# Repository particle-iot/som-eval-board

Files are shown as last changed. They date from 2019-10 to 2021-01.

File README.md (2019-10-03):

# M.2 SoM Evaluation Board

*Hardware repository for the M.2 SoM evaluation board*

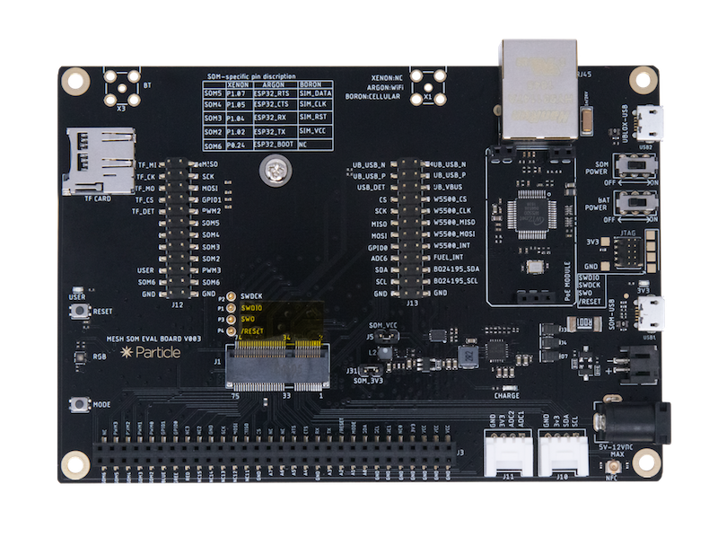
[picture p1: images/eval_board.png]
Eval Board


The description of the board and its features can be found in the documentation:

[https://docs.particle.io/datasheets/cellular/b-series-eval-board/](https://docs.particle.io/datasheets/cellular/b-series-eval-board/)

In this repository you can find the following directories:

- eagle: The [Eagle CAD](https://www.autodesk.com/products/eagle/overview) design files for this board. Note that it is a 4-layer board so you won't be able to edit it with the free version.
- gerbers: The Gerber files used to manufacture the board.
- bom: The bill of materials (Excel spreadsheet).

Other useful resources include:

- [Creating your first SoM board tutorial](https://docs.particle.io/tutorials/hardware-projects/som-first-board/).
- [AN001 Basic SoM Design](https://github.com/particle-iot/app-notes/tree/master/AN001-Basic-SoM-Design) is a simple SoM base board. Like a Boron it can be powered by LiPo battery, USB, or an external DC supply. It includes: RGB LED, bq24195 PMIC, MAX17043 Fuel Gauge, USB Connector, LiPo Connector (JST-PH), and M.2 SoM Connector. It is a 2-layer board.

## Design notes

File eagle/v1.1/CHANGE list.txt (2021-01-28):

2020/2/28
M2EVB change list:

1.Change the stand-off package,the stand-off hole size is 3.6mm.The pcb package hole size is 3.75mm.

2.change silkscreen Font into vector

3.Change silkscreen `UBLOX USB` to `Cellular-USB`

4.Add silkscreen `SOM AREA`

5.Connect unused pins on M.2 to the header,Including these signals:
SOM0,SOM1,SOM12~SOM18.

6.Change the 60pin of the 60pin female connector from NC to SOM9, 
and 59pin from SOM9 to GND for easy connection with SIM adapter

7.Change the SMA connector silk screen to "ANTENNA_1", "ANTENNA_2", "V1.1" & "CELLULAR_USB"

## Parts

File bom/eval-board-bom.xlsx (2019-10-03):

Description | Designator | Qty | MFG | MPN | MFG1 | MPN1
Ceramic Capacitor X6S 1uF 0402 6.3V ±10% ROHS | C2 | 1 | Samsung | CL05X105KQ5NNNC
CAP CER 0.1uF 16V X7R 0402 10% | C1,C6,C7,C13,C18,C19,C20,C21,C22,C23,C24,C30,C33 | 13 | Fenghua | 0402B104K160NT
CAP CER 100pF 50V X7R 0402 10% | C3 | 1 | Fenghua | 0402B101K500NT
CAP CER 10nF 16V X5R 0402 10% | C14,C26,C54 | 3 | Fenghua | 0402X105K160NT
CAP CER10uF 10V X5R 0603 10% | C4,C5,C25,C28,C58,C59,C63 | 7 | Fenghua | 0603X106K100NT
CAP CER 10UF 25V X5R 0603 20% | C56,C57,C62,C64 | 4 | Yageo | CC0603MRX5R8BB106 | Samsung | CL10A106MA8NRNC
CAP CER 18PF 50V C0G/NP0 0402 5% | C11,C12 | 2 | Samsung | CL05C180JB5NNNC
CAP CER 1000PF 2KV(3KV) X7R 1808 10% | C29 | 1 | FengHua | 1808B102K202NT | Johanson | 302R29W102KV4E
CAP CER 1000PF 50V X7R 0402 10% | C47 | 1 | SAMSUNG | CL05B102JB5NNNC
CAP CER 1UF 25V X5R 0402 10% | C55,C60 | 2 | Samsung | CL05A105KA5NQNC | FH | 0402F105M250NT
CAP CER 4.7uF 6.3V X5R 0603 10% Low ESR<70mohms | C31,C65 | 2 | Yageo | CC0603KRX5R5BB475
CAP CER 47NF 6.3V X5R 0201 10% | C17 | 1 | Murata | GRM033R60J473KE19D | FH | 0201X473K6R3NT
CAP CER 6.8nF 6.3V X7R 0402 10% | C15,C16 | 2 | muRata | GRM155R71H682KA88D
RES SMD 0 OHM JUMPER 1/16W 0402 | R5,R6,R17,R18,R20,R50, | 6 | Fenghua | RC-02000JT | YAGEO | RC0402JR-070RL
RES SMD 100K OHM 5% 1/8W 0603 | R4,R7 | 2 | Yageo | RC0603JR-07100KL
RES SMD 10K OHM 5% 1/16W 0402 | R2,R3,R10,R11,R34,R49,R24,R25,R60 | 9 | Fenghua | RC-02W103JT | YAGEO | RC0402JR-0710KL
RES SMD 10 OHM 1% 1/16W 0402 | R32 | 1 | UniOhm | 0402WGF100JTCE | YAGEO | RC0402FR-0710RL
RES ARRAY 4 RES 10K OHM 0804 1% 4RES | RN1,RN2 | 2 | YAGEO | YC124-FR-0710KL
RES SMD 0.001Ω OHM 1% 1W 2512 | R61 | 1 | YAGEO | PA2512FKF070R001E
RES SMD 12.4K OHM 1% 1/16W 0402 | R23 | 1 | YAGEO | RC0402FR-0712K4L
RES SMD 150 OHM 1% 1/16W 0402 12.4K | R16 | 1 | Yageo | RC0402FR-07150RL
RES SMD 1K OHM 5% 1/16W 0402 | R8,R12,R13,R14,R15,R52,R44,R54,R55 | 9 | Fenghua | RC-02W102JT
RES SMD 1M OHM 5% 1/16W 0402 | R26 | 1 | UniOhm | 0402WGF1004TCE | YAGEO | RC0402JR-071ML
RES SMD 330R OHM 1% 1/16W 0402 | R33,R47,R48 | 3 | Fenghua | RC-02W3300FT | YAGEO | RC0402FR-07330RL
RES SMD 33R OHM 1% 1/16W 0402 | R42,R43,R45,R46,R56,R19,R51,R53,R57 | 9 | UniOhm | 0402WGF330JTCE | YAGEO | RC0402FR-0733RL
RES SMD 47k OHM 1% 1/16W 0402 | R9,R28,R29 | 3 | YAGEO | RC0402FR-0747KL
RES SMD 49R9 OHM 1% 1/16W 0402 | R31,R39,R40,R41 | 4 | YAGEO | RC0402FR-0749R9L
RES SMD 4.7K OHM 5% 1/20W 0201 | R30,R36 | 2 | Yageo | RC0201JR-074K7L
RES SMD 5K49 OHM 1% 1/16W 0402 | R35 | 1 | Fenghua | RC-02W5491FT | Yageo | RC0402FR-075K49L
FIXED IND 2.2UH 4A 61 MOHM SMD | L7 | 1 | Bourns,Inc. | SRP4020TA-2R2M
CRYSTAL 25.0000MHZ 20PF 4-SMD 3225 20PPM | Y1 | 1 | YXC | X322525MSB4SI | EPSON | FA-238 25.0000MD-G3
FERRITE BEAD 100 OHM@100MHz 0.8A 0805 | L4 | 1 | Sunload | GZ2012D101TF
RESET FUSE 1A 6V 0805 | F1,F2 | 2 | JDTFuse | ASMD0805-100
4P-2.0-90D | J10,J11 | 2 | Kaweei | CW-A2008R-04
connector 2x5pin 1.27mm pitch SMD ROHS | DEBUG | 1 | Kaweei | P6014A-M2GC-030-10-RC
connector 2x12pin 2.54mm pitch SMD ROHS | J35 | 1 | Kaweei | P210-MFGN-058-24-PRC
connector 2x6pin 2.54mm pitch SMD ROHS | J12 | 1 | Kaweei | P210-MFGN-058-12-PRC
DC-005 outer diameter 6.4 inner core 3 feet high temperature 2.1MMDC DC power socket female | J2 | 1 | Kaweei | CDJ-D005B-2.0
female header connector 2x30pin 2.54mm pitch SMD ROHS | J3 | 1 | Kaweei | F291-MGN-D072-60-PRC
LIPO BATTERY CONNECTOR | J4 | 1 | Kaweei | CW2001-02T-M01-D
connector 2pin header，2.54mm | J5,J7,J31 | 3 | Kaweei | P101-SGP-060-030-02
connector 3pin female header，2.54mm | J14 | 1 | Kaweei | F101-SGP-D030-03
connector 2pin female header，2.54mm | J15,J16 | 2 | Kaweei | F101-SGP-D030-02
Self-elastic Internal soldering TF connector 0046_15TW-882 | X4 | 1 | Kaweei | CTFD003-S-02-BD
MSS-22D16 pin small toggle switch six feet | S1,S4 | 2
POGOPIN 2.0*3.2 | P1,P2,P3,P4 | 4 | Huarong | 2.0*3.2（需要问供应商是否可以编带）
NGFF carrier NGFF M.2 E-KEY height 4.2H SSD solid state drive slot card connector | J1 | 1 | LOTES | 181004 | TE | TE 2199230-4
LED blue 0603 ROHS | LED1,LED2 | 2 | Everlight | 19-217/BHC-ZM1N2TY/3T | BrtLED | BL-HB336G-TRB
FERRITE BEAD 30 OHM@100MHz 2A 0603 1LN | L1 | 1 | Sunload | GZ1608D300TF
ESD DIODE/BPESD0402-05ST | Z1,Z2,Z3,Z4,Z5,Z6 | 6 | BORN | BPESD0402-05ST
RJ45 Connector | RJ45 | 1 | HANRUN | HY931147A
P-MOS -12V 4.3A SOT23 ROHS | Q2,Q3 | 2 | IR | IRLML6401TRPBF | Force mos | ME2333
IC 2-WIRE FG MODEL GAUGE LO BATT | U13 | 1 | Maxim | MAX17043G+T
IC CHRG MGMT LI-ION/POL 24VQFN | U14 | 1 | TI | BQ24195
USB Micro Connector with Slots, SMD ROHS | USB1,USB2 | 2 | Kaweei | CMCUSB-5BFM14G-01-D
FIXED IND 2.2UH 1.5A 72 MOHM SMD | L2 | 1 | TAIYO | NRS3015T2R2MNGH | TaiyoYuden | NR3015T2R2M
LED RGB, Common Anode, Clear, 4PLCC SMD ROHS | RGB | 1 | CREE | CLMVC-FKA-CA1E1L81BB7C3C3
DIODE SCHOTTKY 30V 3A DO220AA | D3,D4,D7 | 3 | VISHAY | SS3P3-M3/84A
Tactile Switch, Black Button 2.5mm height | BUTTON,RESET | 2 | HAOYU | TS-1185A-025C
CONN UMC RCPT STR 50 OHM SMD | NFC | 1 | Kaweei | P1163-0140R
IC CTLR 3-1 ETH TCP/IP 48LQFP | U1 | 1 | wiznet | W5500
85mΩ High Function Power Switch | U2 | 1 | Torex | XC8107AC20MR-G
Synchronous Step-Down DC/DC Converters | U3 | 1 | Torex | XC9258B33CER-G
Schottky Diode B5819w SL 1A 40V ROHS | D8 | 1 | CJ江苏长电 | B5819w SL
LED super yellow 0603 ROHS | D5 | 1 | Everlight | 19-217/Y5C-AP1Q2/3T | BrtLed(佰鸿) | BL-HKC36G-AV-TRB
nut(M3,custom made) |  | 1 | Hengxintai | M3
PCB for SOM EVA 4 layers PCB 130*90mm, black matte PCB w/ cyan silkscreen |  | 1 | Benlida
Short circuit cap |  | 22 | Risym | 2.54mm black
USB Micro-B Cable |  | 1 | Hop | USB cable
Grove - Temperature & Humidity Sensor |  | 1 | Seeed | 101020011
Anti-collision rubber 8*2.5 |  | 4 | Shida | 8*2.5
screw(custom made) 3*3 |  | 2 | Hengxintai | 3*3
metal spacer M2.5*5-M |  | 2 | Hengxintai | M2.5*5-M
SMA connector with IPEX cable 40 mm | X1, X3 | 2 | Kaweei

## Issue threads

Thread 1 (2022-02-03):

Request: Sample code for the temperature/humidity sensor

TheCre8r, 2022-02-03:
I am having some issues getting the temperature/humidity sensor to work. Do you have some example code?

Thanks!

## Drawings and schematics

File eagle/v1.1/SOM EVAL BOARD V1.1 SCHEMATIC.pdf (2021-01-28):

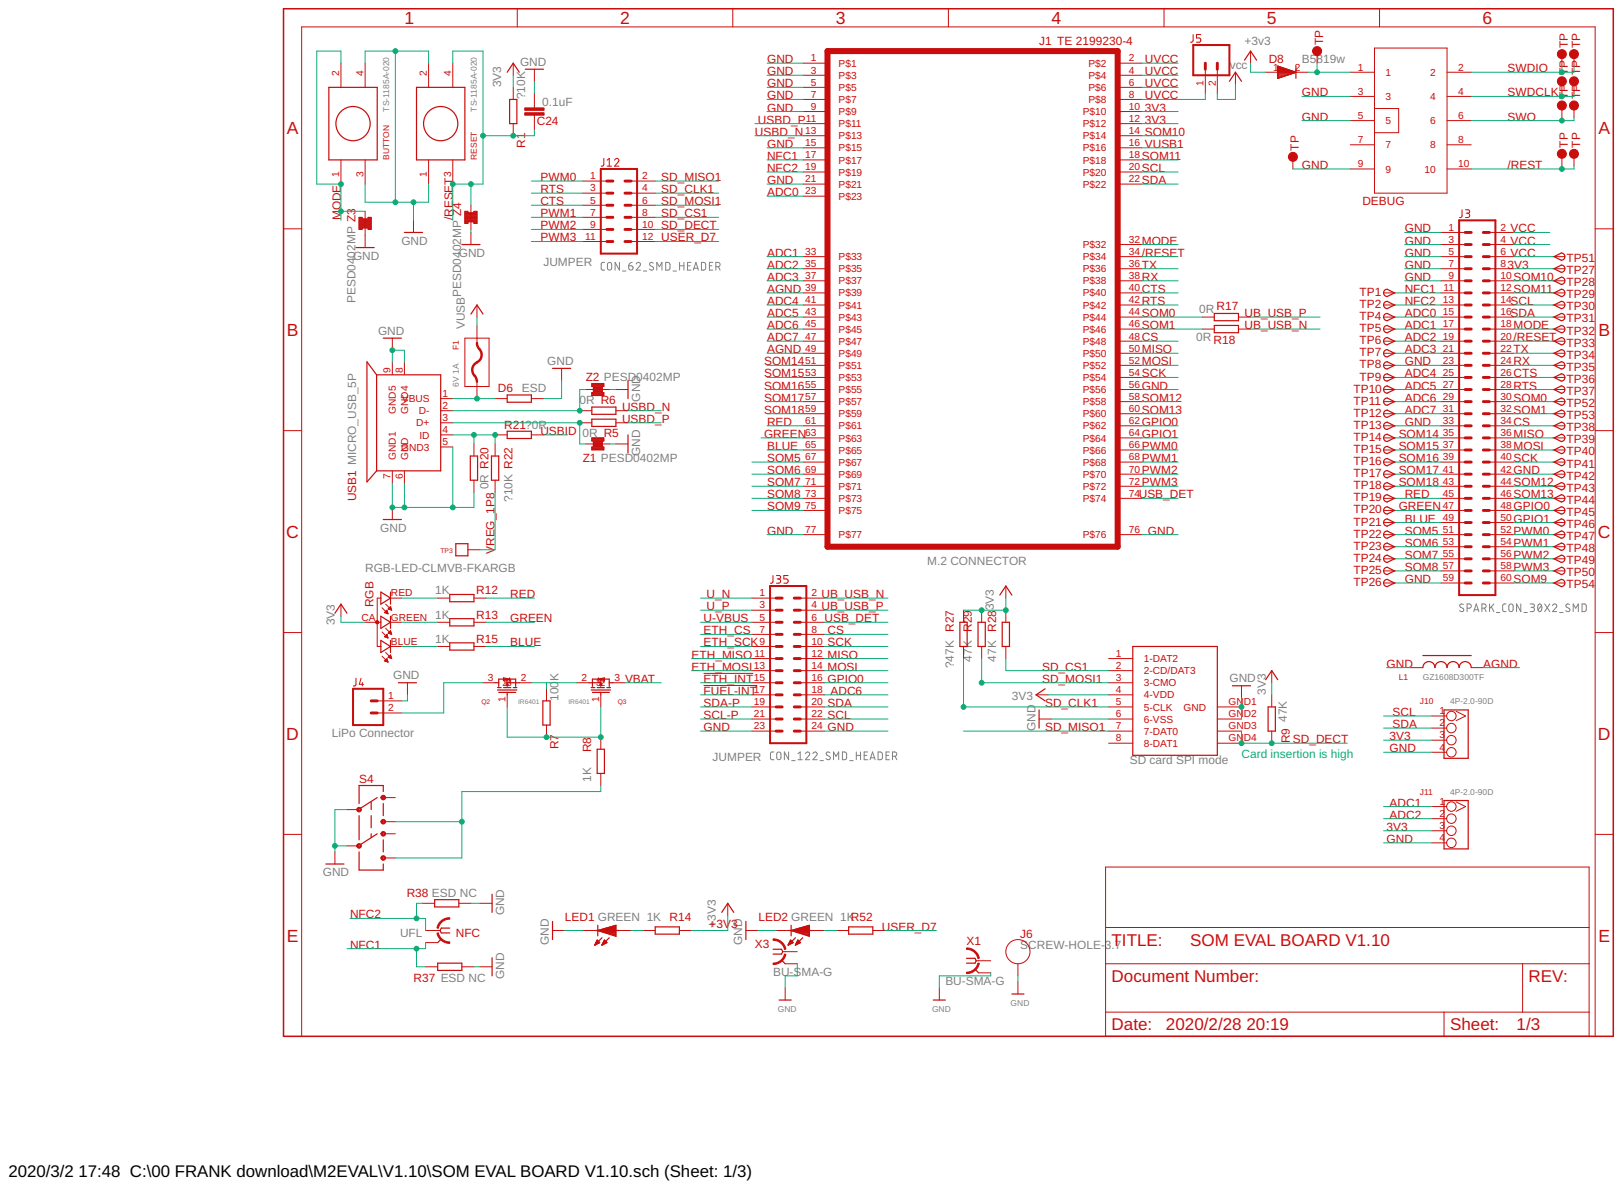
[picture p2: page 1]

RGB-LED-CLMVB-FKARGB

8-DAT1
SD card SPI mode

Card insertion is high

Document Number: | REV:

Date: 2020/2/28 20:19 | Sheet: 1/3

2020/3/2 17:48 C:\00 FRANK download\M2EVAL\V1.10\SOM EVAL BOARD V1.10.sch (Sheet: 1/3)

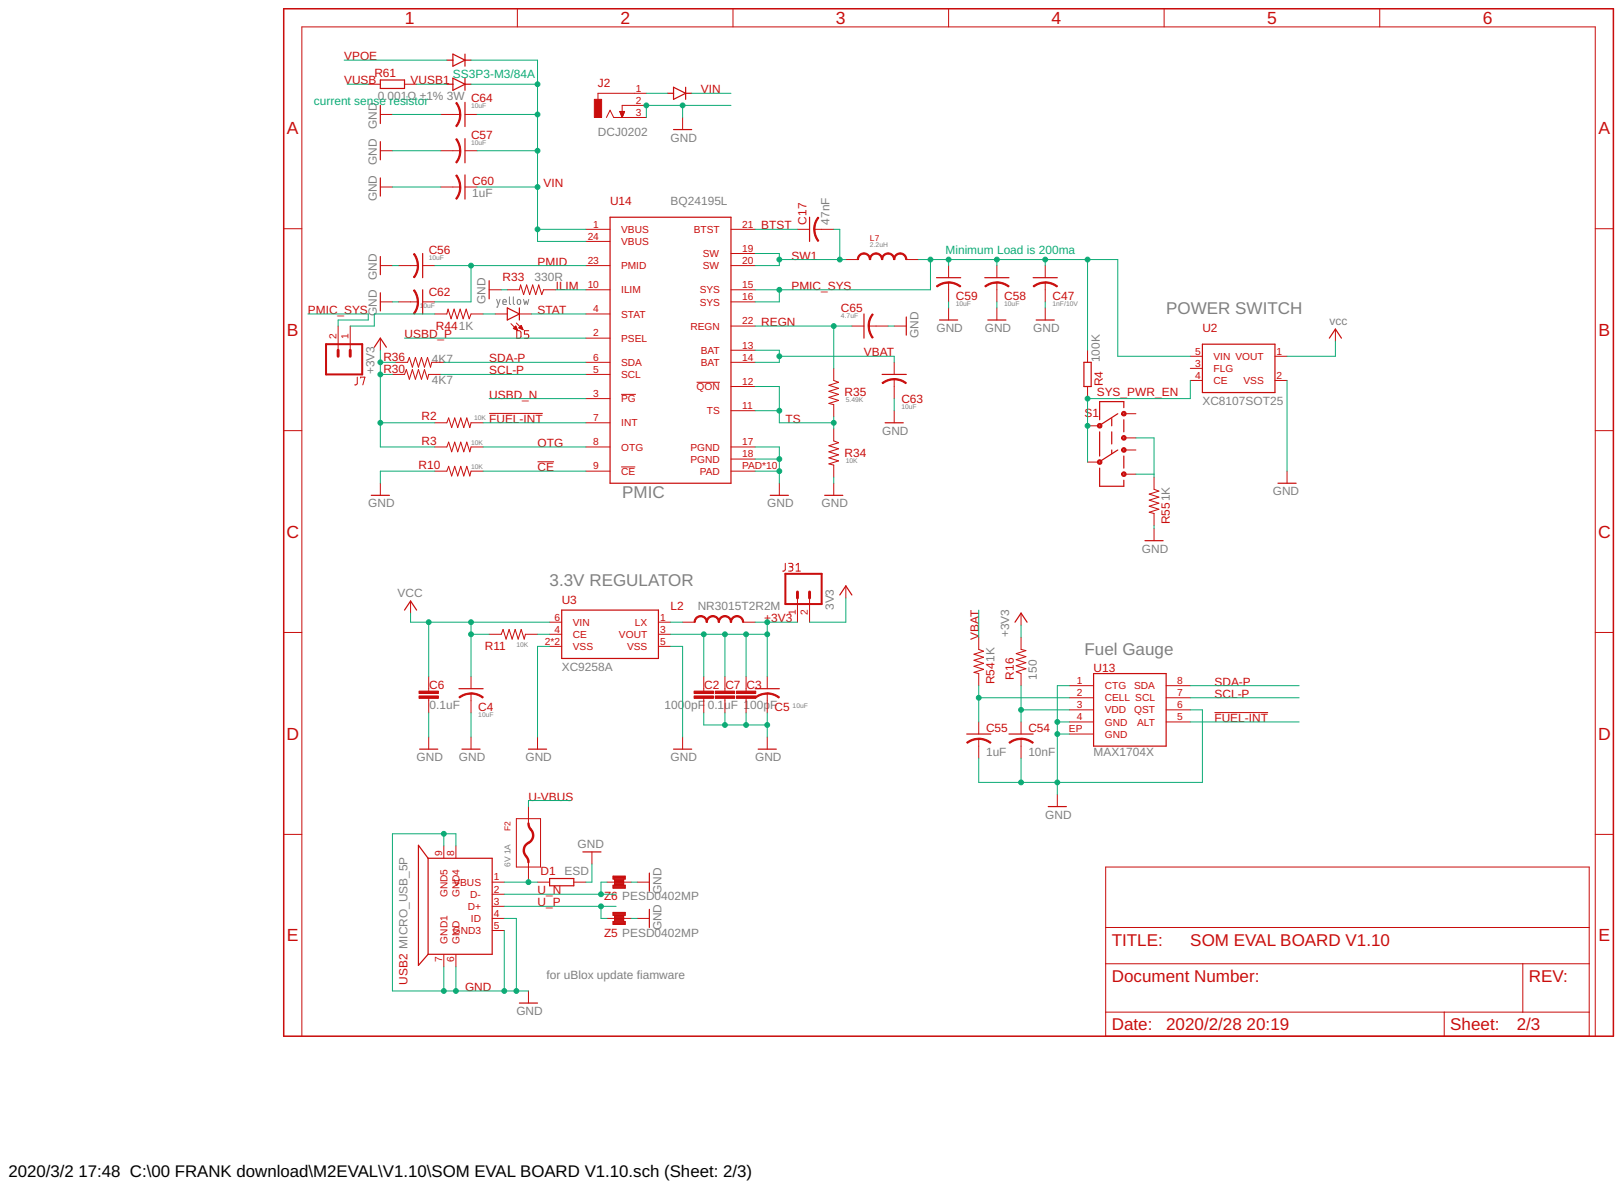
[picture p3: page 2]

for uBlox update fiamware

Document Number: | REV:

Date: 2020/2/28 20:19 | Sheet: 2/3

2020/3/2 17:48 C:\00 FRANK download\M2EVAL\V1.10\SOM EVAL BOARD V1.10.sch (Sheet: 2/3)

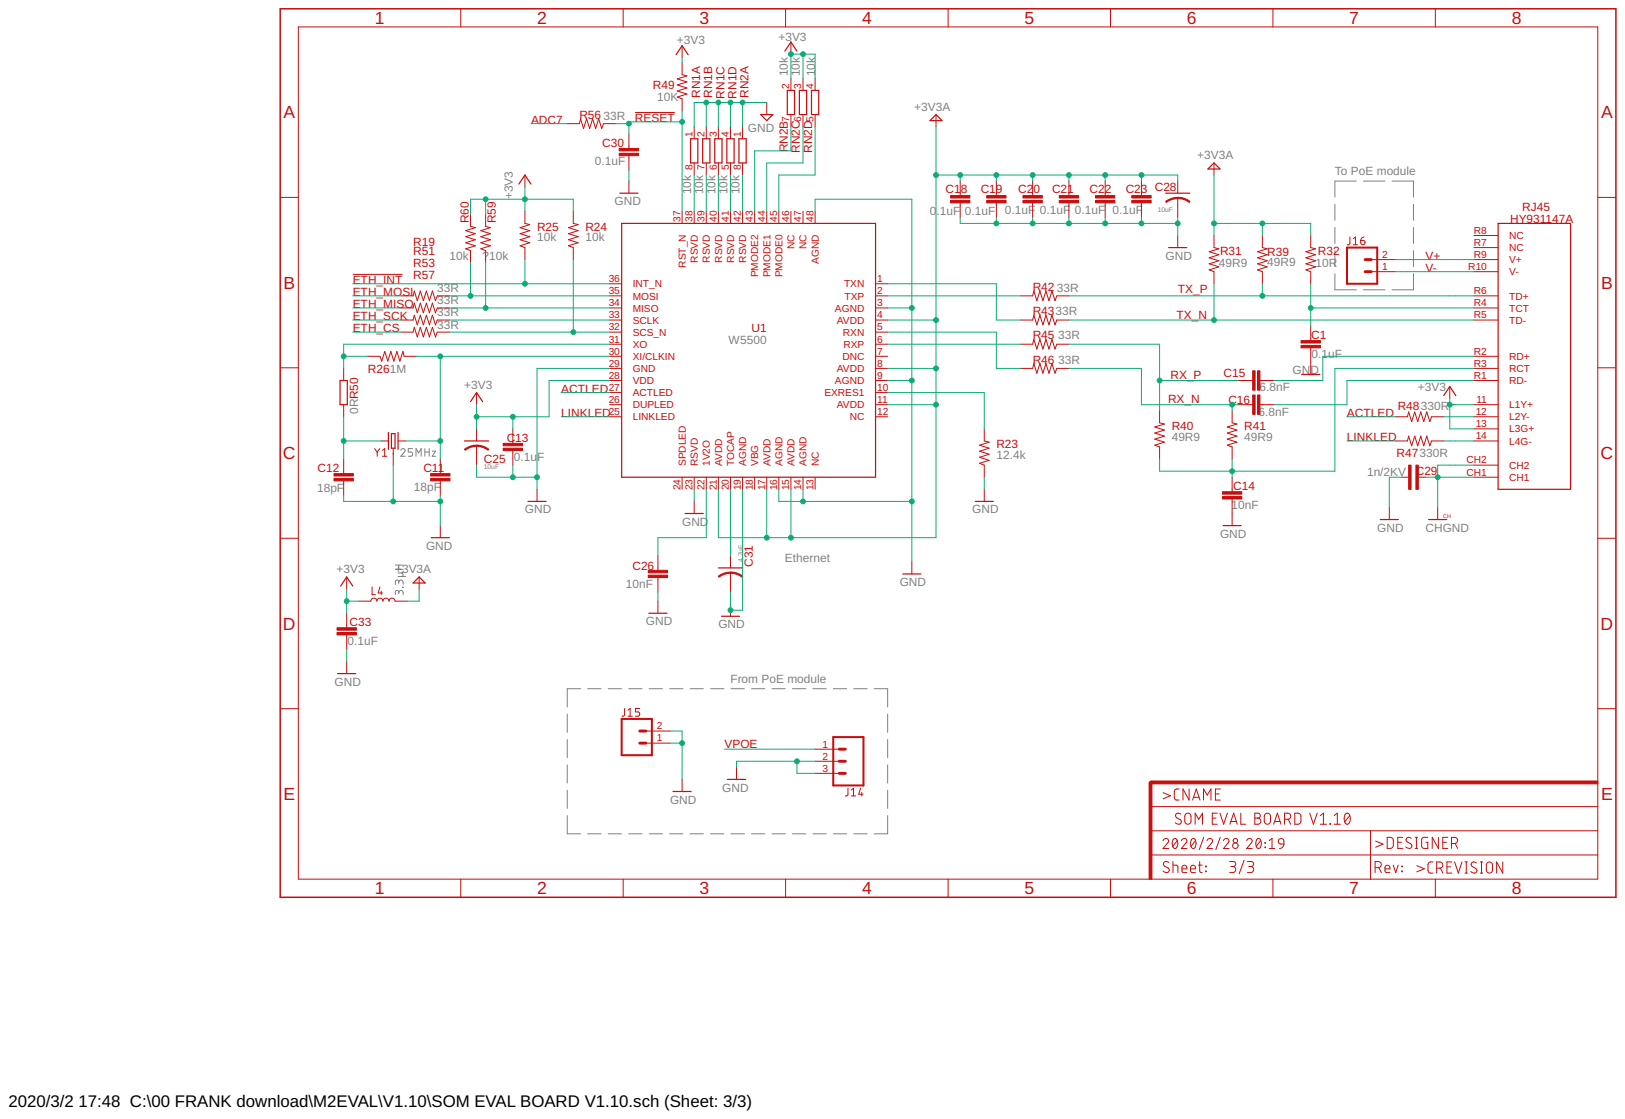
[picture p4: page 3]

RCT R3 RD+ R2 RD- R1

2020/3/2 17:48 C:\00 FRANK download\M2EVAL\V1.10\SOM EVAL BOARD V1.10.sch (Sheet: 3/3)

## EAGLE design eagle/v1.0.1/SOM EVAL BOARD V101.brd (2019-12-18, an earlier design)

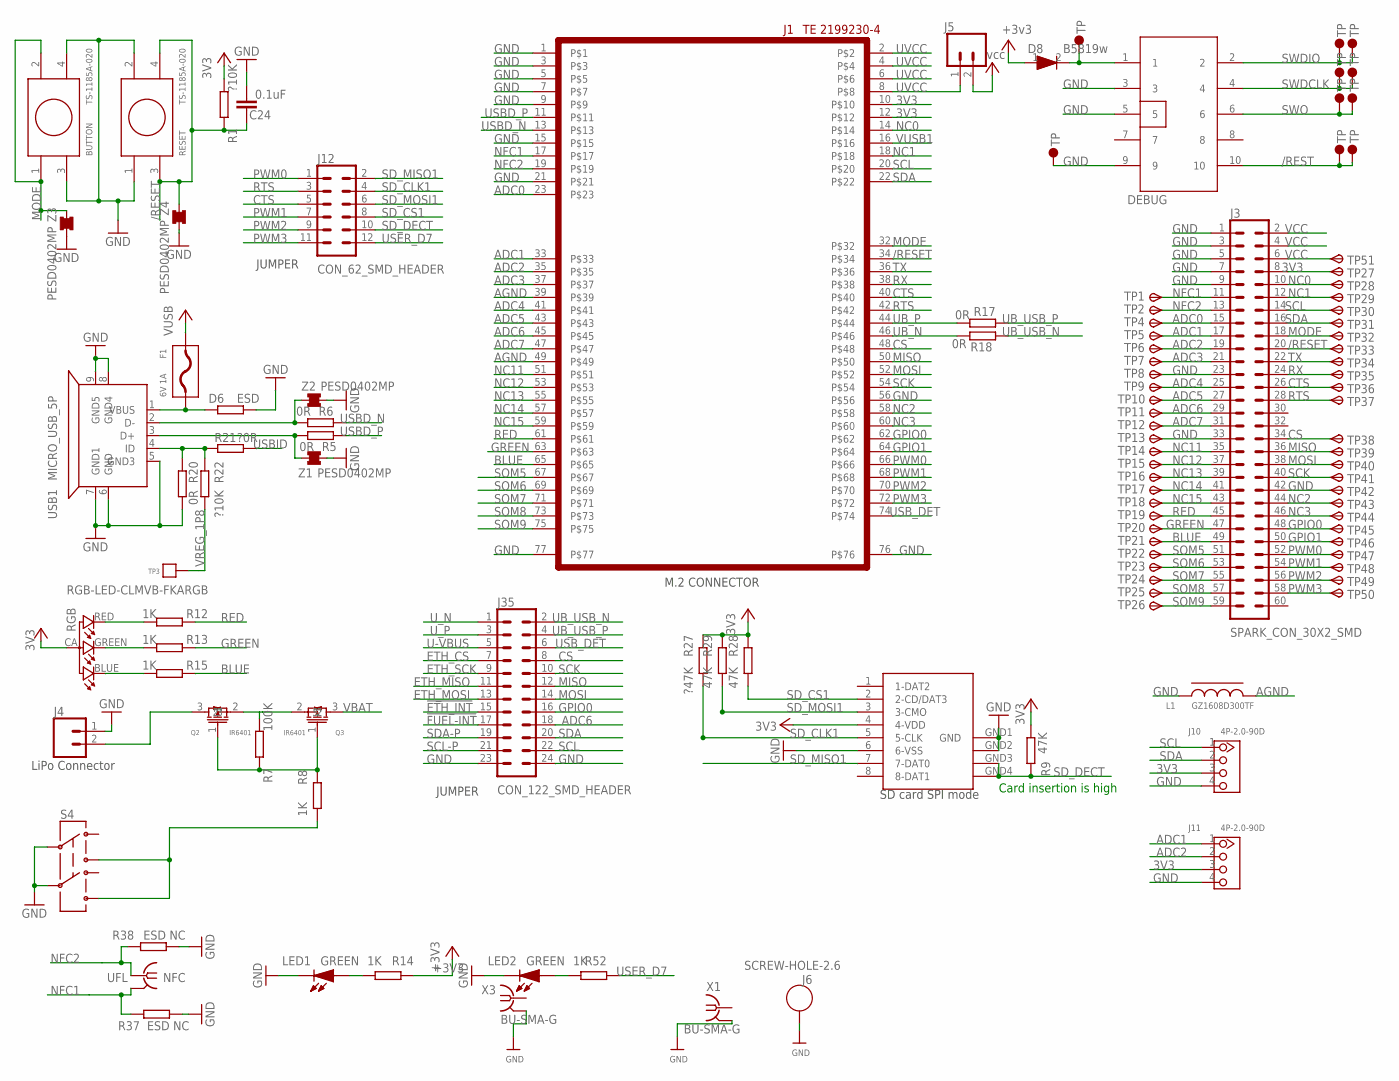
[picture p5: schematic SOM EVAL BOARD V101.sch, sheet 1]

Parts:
BUTTON: TS-1185A-020
C24: 0.1uF; C0402_B
D6: ESD; R-0402S
D8: B5819w; SOD-123
DEBUG: CON5X2; CON5X2_1.27
F1: 6V 1A; F0805
J1: TE 2199230-4; M.2EKEY
J3: SPARK_CON_30X2_SMD
J4: CONN_02-JST-2MM-SMT; JST-2-SMD
J5: CONN_02; 1X02
J6: SCREW-HOLE-2.6
J10, J11: 4P-2.0-90D; HW4-2.0-90D
J12: CON_62_SMD_HEADER; CON_6*2_SMD_HEADER
J35: CON_122_SMD_HEADER; CON_12*2_SMD_HEADER
L1: GZ1608D300TF; R-0603A
LED1, LED2: GREEN; LED0603
NFC: UFL; IPEX-20279-001E
P1, P2, P3, P4: SPARK_POGOPIN; SPARK_POGO-2.0
Q2, Q3: IR6401; SOT-23
R1, R22: ?10K; R-0402S
R5, R6, R17, R18, R20: 0R; R-0402S
R7: 100K; R0603
R8, R12, R13, R14, R15, R52: 1K; R-0402S
R9, R28, R29: 47K; R-0402S
R21: ?0R; R-0402S
R27: ?47K; R-0402S
R37, R38: ESD NC; R-0402S
RESET: TS-1185A-020
RGB: RGB-LED-CLMVB-FKARGB; PLCC4-2MM-RGB
S4: SWITCH-DPDT; SWITCH-2.5X3.2-6
TP1, TP2, TP4, TP5, TP6, TP7, TP8, TP9, TP10, TP11, TP12, TP13, TP14, TP15, TP16, TP17, TP18, TP19, TP20, TP21, TP22, TP23, TP24, TP25, TP26, TP27, TP28, TP29, TP30, TP31, TP32, TP33, TP34, TP35, TP36, TP37, TP38, TP39, TP40, TP41, TP42, TP43, TP44, TP45, TP46, TP47, TP48, TP49, TP50, TP51: TPSB1,27; B1,27
TP3: TPTP; TP
U$1, U$2, U$9, U$10, U$11, U$12: TP2; TP70_BOT
USB1: MICRO_USB_5P; MICRO_USB
X1, X3: BU-SMA-G
X4: 0046_15TW-882; SDCARD-15TW-8821
Z1, Z2, Z3, Z4: PESD0402MP; SMD-0402MP

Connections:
3V3: J1.10, J1.12, J3.8, J10.3, J11.3, R1.2, R9.2, R27.1, R28.1, R29.1, RGB.CA (1), TP27.TP, X4.4 (4-VDD); also elsewhere on the board
!ETH_INT: J35.15; also elsewhere on the board
!FUEL-INT: J35.17; also elsewhere on the board
+3V3: D8.1, R14.1; also elsewhere on the board
/RESET: C24.2, J1.34, J3.20, R1.1, RESET.3, RESET.4, TP33.TP, Z4.2
/REST: DEBUG.10, P4.P$2, U$12.P$1
ADC0: J1.23, J3.15, TP4.TP
ADC1: J1.33, J3.17, J11.1, TP5.TP
ADC2: J1.35, J3.19, J11.2, TP6.TP
ADC3: J1.37, J3.21, TP7.TP
ADC4: J1.41, J3.25, TP9.TP
ADC5: J1.43, J3.27, TP10.TP
ADC6: J1.45, J3.29, J35.18, TP11.TP
ADC7: J1.47, J3.31, TP12.TP; also elsewhere on the board
AGND: J1.39, J1.49, L1.2
BLUE: J1.65, J3.49, R15.1, TP21.TP
CS: J1.48, J3.34, J35.8, TP38.TP
CTS: J1.40, J3.26, J12.5, TP36.TP
D+: R5.2, USB1.3 (D+), Z1.2
D-: R6.2, USB1.2 (D-), Z2.2
ETH_CS: J35.7; also elsewhere on the board
ETH_MISO: J35.11; also elsewhere on the board
ETH_MOSI: J35.13; also elsewhere on the board
ETH_SCK: J35.9; also elsewhere on the board
GND: BUTTON.3, BUTTON.4, C24.1, D6.1, DEBUG.3, DEBUG.5, DEBUG.9, J1.1, J1.3, J1.5, J1.7, J1.9, J1.15, J1.21, J1.56, J1.76, J1.77, J3.1, J3.3, J3.5, J3.7, J3.9, J3.23, J3.33, J3.42, J4.1 (2), J6.P$1, J10.4, J11.4, J35.23, J35.24, L1.1, LED1.2 (K), LED2.2 (K), R20.2, R37.2, R38.1, RESET.1, RESET.2, S4.2, S4.5, TP8.TP, TP13.TP, TP42.TP, U$2.P$1, USB1.5 (GND3), USB1.6 (GND), USB1.7 (GND1), USB1.8 (GND4), USB1.9 (GND5), X1.2, X1.3 (2), X1.4 (2), X1.5 (2), X3.2, X3.3 (2), X3.4 (2), X3.5 (2), X4.6 (6-VSS), X4.GND1 (GND), X4.GND2 (GND1), Z1.1, Z2.1, Z3.1, Z4.1; also elsewhere on the board
GPIO0: J1.62, J3.48, J35.16, TP45.TP
GPIO1: J1.64, J3.50, TP46.TP
GREEN: J1.63, J3.47, R13.1, TP20.TP
MISO: J1.50, J3.36, J35.12, TP39.TP
MODE: BUTTON.1, BUTTON.2, J1.32, J3.18, TP32.TP, Z3.2
MOSI: J1.52, J3.38, J35.14, TP40.TP
unnamed: R20.1, R21.1, R22.1, USB1.4 (ID)
unnamed: R12.2, RGB.RED (4)
unnamed: R8.2, S4.3, S4.6
unnamed: D8.2, DEBUG.1, U$1.P$1
unnamed: J4.2 (1), Q2.3
unnamed: D6.2, F1.P$1 (1), USB1.1 (VBUS)
unnamed: LED1.1 (A), R14.2
unnamed: R15.2, RGB.BLUE (2)
unnamed: R13.2, RGB.GREEN (3)
unnamed: LED2.1 (A), R52.2
unnamed: Q2.2, Q3.2, R7.2
unnamed: Q2.1, Q3.1, R7.1, R8.1
NC0: J1.14, J3.10, TP28.TP
NC1: J1.18, J3.12, TP29.TP
NC2: J1.58, J3.44, TP43.TP
NC3: J1.60, J3.46, TP44.TP
NC11: J1.51, J3.35, TP14.TP
NC12: J1.53, J3.37, TP15.TP
NC13: J1.55, J3.39, TP16.TP
NC14: J1.57, J3.41, TP17.TP
NC15: J1.59, J3.43, TP18.TP
NFC1: J1.17, J3.11, NFC.2@1 (GND), NFC.2@2 (GND), R37.1, TP1.TP
NFC2: J1.19, J3.13, NFC.1, R38.2, TP2.TP
PWM0: J1.66, J3.52, J12.1, TP47.TP
PWM1: J1.68, J3.54, J12.7, TP48.TP
PWM2: J1.70, J3.56, J12.9, TP49.TP
PWM3: J1.72, J3.58, J12.11, TP50.TP
RED: J1.61, J3.45, R12.1, TP19.TP
RTS: J1.42, J3.28, J12.3, TP37.TP
RX: J1.38, J3.24, TP35.TP
SCK: J1.54, J3.40, J35.10, TP41.TP
SCL: J1.20, J3.14, J10.1, J35.22, TP30.TP
SCL-P: J35.21; also elsewhere on the board
SDA: J1.22, J3.16, J10.2, J35.20, TP31.TP
SDA-P: J35.19; also elsewhere on the board
SD_CLK1: J12.4, R27.2, X4.5 (5-CLK)
SD_CS1: J12.8, R28.2, X4.2 (2-CD/DAT3)
SD_DECT: J12.10, R9.1, X4.GND3 (GND2), X4.GND4 (GND3)
SD_MISO1: J12.2, X4.7 (7-DAT0)
SD_MOSI1: J12.6, R29.2, X4.3 (3-CMO)
SOM5: J1.67, J3.51, TP22.TP
SOM6: J1.69, J3.53, TP23.TP
SOM7: J1.71, J3.55, TP24.TP
SOM8: J1.73, J3.57, TP25.TP
SOM9: J1.75, J3.59, TP26.TP
SWDCLK: DEBUG.4, P2.P$2, U$10.P$1
SWDIO: DEBUG.2, P1.P$2, U$9.P$1
SWO: DEBUG.6, P3.P$2, U$11.P$1
TX: J1.36, J3.22, TP34.TP
U-VBUS: J35.5; also elsewhere on the board
UB_N: J1.46, R18.2
UB_P: J1.44, R17.2
UB_USB_N: J35.2, R18.1
UB_USB_P: J35.4, R17.1
USBD_N: J1.13, R6.1; also elsewhere on the board
USBD_P: J1.11, R5.1; also elsewhere on the board
USBID: R21.2
USB_DET: J1.74, J35.6
USER_D7: J12.12, R52.1
UVCC: J1.2, J1.4, J1.6, J1.8, J5.1
U_N: J35.1; also elsewhere on the board
U_P: J35.3; also elsewhere on the board
VBAT: Q3.3; also elsewhere on the board
VCC: J3.2, J3.4, J3.6, J5.2, TP51.TP; also elsewhere on the board
VREG_1P8: R22.2, TP3.P$1
VUSB: F1.P$2 (2); also elsewhere on the board
VUSB1: J1.16; also elsewhere on the board

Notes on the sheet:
SD card SPI mode
LiPo Connector
JUMPER
Card insertion is high
M.2 CONNECTOR

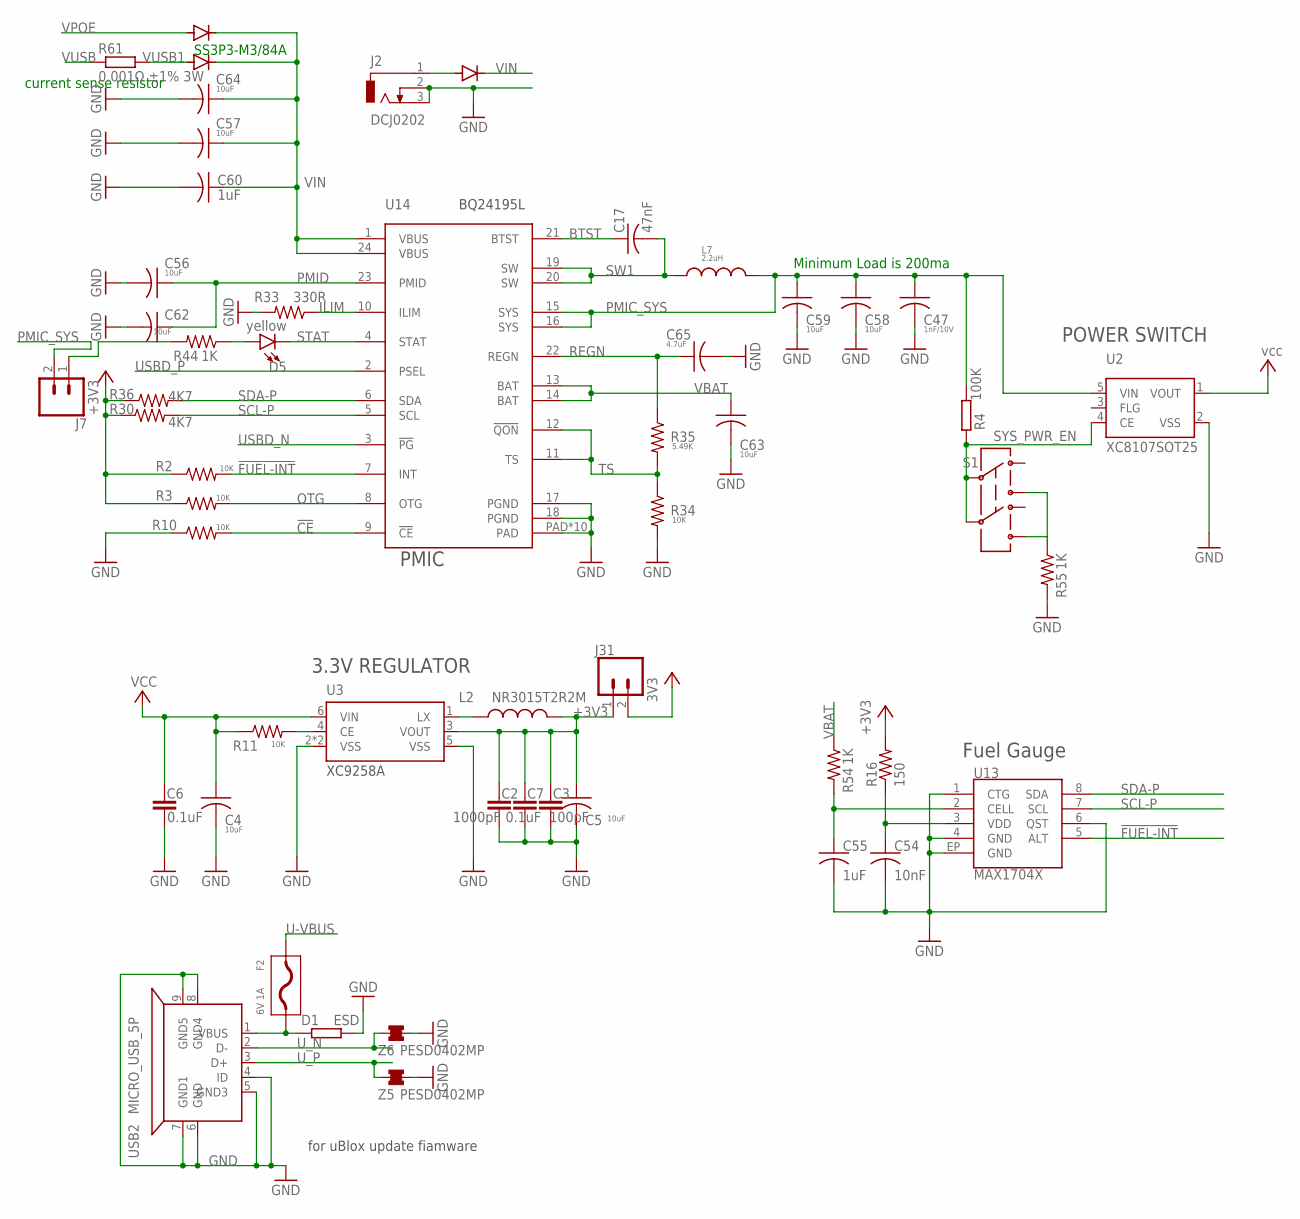
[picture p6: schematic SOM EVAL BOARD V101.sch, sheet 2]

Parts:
C2: 1000pF; C0402_B
C3: 100pF; C0402_B
C4, C5, C56, C57, C58, C59, C62, C63, C64: 10uF; C0603_B
C6, C7: 0.1uF; C0402_B
C17: 47nF; C0201_B
C47: 1nF/10V; C0402_B
C54: 10nF; C0402_B
C55, C60: 1uF; C0402_B
C65: 4.7uF; C0603_B
D1: ESD; R-0402S
D3, D4, D7: SS3P3-M3/84A; DIODE-DO-220AA_NT(SMP)
D5: yellow; LED-0603
F2: 6V 1A; F0805
J2: DCJ0202
J7, J31: CONN_02; 1X02
L2: NR3015T2R2M; INDUCTOR-VLS-E
L7: 2.2uH; INDUCTOR-4040
R2, R3, R10, R11, R34: 10K; R0402_B
R4: 100K; R0603
R16: 150; 0402-RES
R30, R36: 4K7; C0201_B
R33: 330R; R0402_B
R35: 5.49K; R0402_B
R44, R54, R55: 1K; R0402_B
R61: 0.001Ω ±1% 3W; R2512
S1: SWITCH-DPDT; SWITCH-2.5X3.2-6
U2: XC8107SOT25; SOT25
U3: XC9258A; USP-6C
U13: MAX1704X; TDFN-8
U14: BQ24195L; QFN24
USB2: MICRO_USB_5P; MICRO_USB
Z5, Z6: PESD0402MP; SMD-0402MP

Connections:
3V3: J31.2; also elsewhere on the board
!CE: R10.2, U14.9 (!CE)
!FUEL-INT: R2.2, U13.5 (ALT), U14.7 (INT); also elsewhere on the board
+3V3: C2.2, C3.2, C5.1, C7.2, J31.1, L2.P$2 (2), R2.1, R3.1, R16.2, R30.1, R36.1, U3.3 (VOUT); also elsewhere on the board
BTST: C17.1, U14.21 (BTST)
GND: C2.1, C3.1, C4.2, C5.2, C6.1, C7.1, C47.2, C54.2, C55.2, C56.2, C57.2, C58.2, C59.2, C60.2, C62.2, C63.2, C64.2, C65.2, D1.1, J2.2, J2.3, R10.1, R33.2, R34.2, R55.2, U2.2 (VSS), U3.2 (VSS), U3.5 (VSS), U3.P$1 (VSS), U13.1 (CTG), U13.4 (GND), U13.6 (QST), U13.EP (GND), U14.17 (PGND), U14.18 (PGND), U14.PAD, U14.PAD@1 (PAD), U14.PAD@2 (PAD), U14.PAD@3 (PAD), U14.PAD@4 (PAD), U14.PAD@5 (PAD), U14.PAD@6 (PAD), U14.PAD@7 (PAD), U14.PAD@8 (PAD), U14.PAD@9 (PAD), USB2.4 (ID), USB2.5 (GND3), USB2.6 (GND), USB2.7 (GND1), USB2.8 (GND4), USB2.9 (GND5), Z5.1, Z6.1; also elsewhere on the board
ILIM: R33.1, U14.10 (ILIM)
unnamed: D5.A, R44.1
unnamed: J7.1, R44.2
unnamed: D1.2, F2.P$1 (1), USB2.1 (VBUS)
unnamed: L2.P$1 (1), U3.1 (LX)
unnamed: R11.2, U3.4 (CE)
unnamed: R55.1, S1.3, S1.6
unnamed: D7.ANODE, J2.1
unnamed: C54.1, R16.1, U13.3 (VDD)
unnamed: C55.1, R54.2, U13.2 (CELL)
OTG: R3.2, U14.8 (OTG)
PMIC_SYS: C47.1, C58.1, C59.1, J7.2, L7.P$2 (2), R4.2, U2.5 (VIN), U14.15 (SYS), U14.16 (SYS)
PMID: C56.1, C62.1, U14.23 (PMID)
REGN: C65.1, R35.1, U14.22 (REGN)
SCL-P: R30.2, U13.7 (SCL), U14.5 (SCL); also elsewhere on the board
SDA-P: R36.2, U13.8 (SDA), U14.6 (SDA); also elsewhere on the board
STAT: D5.C, U14.4 (STAT)
SW1: C17.2, L7.P$1 (1), U14.19 (SW), U14.20 (SW)
SYS_PWR_EN: R4.1, S1.2, S1.5, U2.4 (CE)
TS: R34.1, R35.2, U14.11 (TS), U14.12 (!QON)
U-VBUS: F2.P$2 (2); also elsewhere on the board
USBD_N: U14.3 (!PG); also elsewhere on the board
USBD_P: U14.2 (PSEL); also elsewhere on the board
U_N: USB2.2 (D-), Z6.2; also elsewhere on the board
U_P: USB2.3 (D+), Z5.2; also elsewhere on the board
VBAT: C63.1, R54.1, U14.13 (BAT), U14.14 (BAT); also elsewhere on the board
VCC: C4.1, C6.2, R11.1, U2.1 (VOUT), U3.6 (VIN); also elsewhere on the board
VIN: C57.1, C60.1, C64.1, D3.CATHODE, D4.CATHODE, D7.CATHODE, U14.1 (VBUS), U14.24 (VBUS)
VPOE: D3.ANODE; also elsewhere on the board
VUSB: R61.1; also elsewhere on the board
VUSB1: D4.ANODE, R61.2; also elsewhere on the board

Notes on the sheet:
POWER SWITCH
3.3V REGULATOR
for uBlox update fiamware
SS3P3-M3/84A
current sense resistor
Fuel Gauge
Minimum Load is 200ma
PMIC

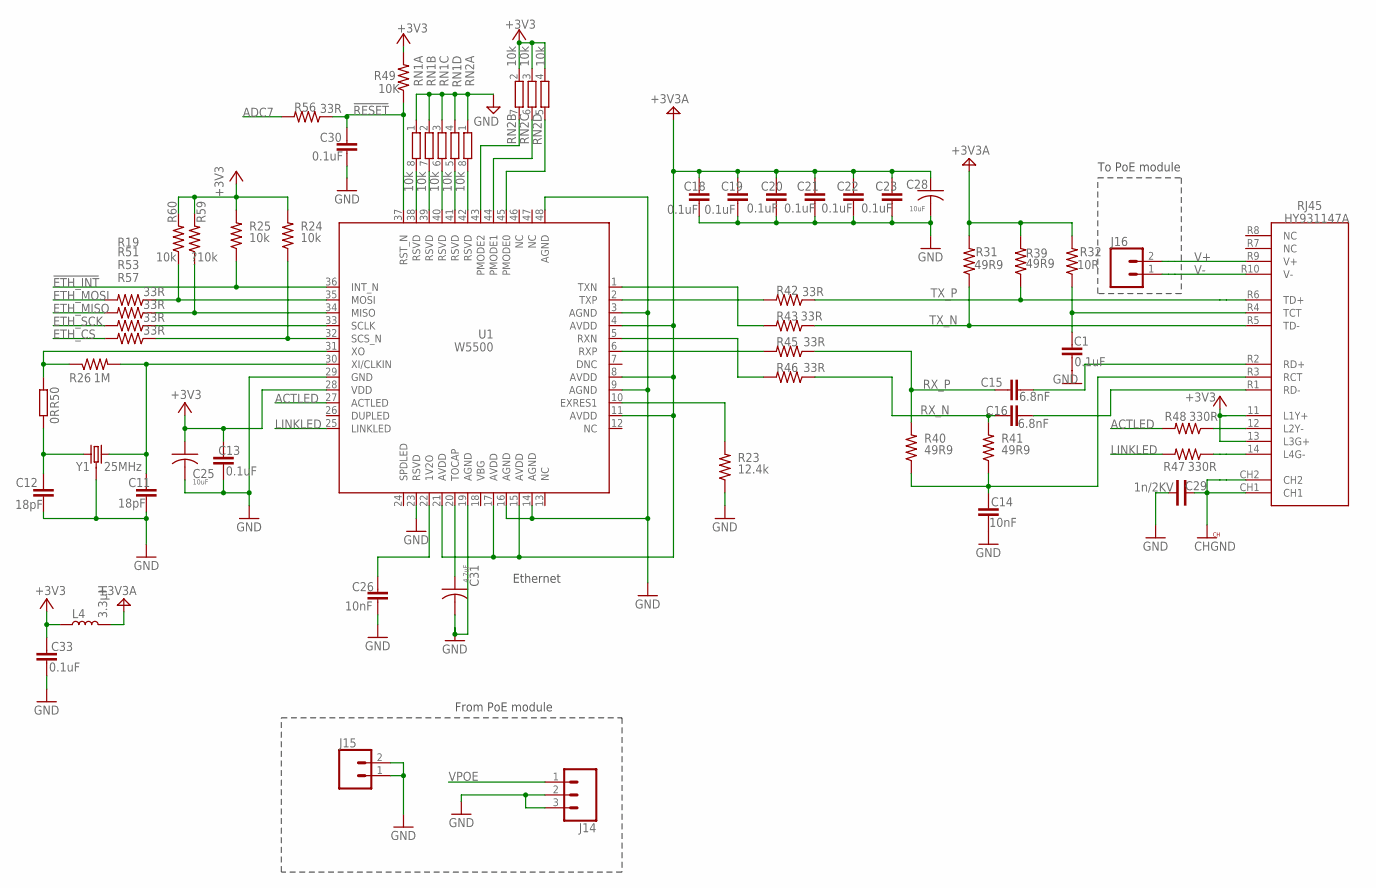
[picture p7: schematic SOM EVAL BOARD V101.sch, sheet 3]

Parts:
C1, C13, C18, C19, C20, C21, C22, C23, C30, C33: 0.1uF; C0402_B
C11, C12: 18pF; C0402_B
C14, C26: 10nF; C0402_B
C15, C16: 6.8nF; C0402_B
C25, C28: 10uF; C0603_B
C29: 1n/2KV; C-1808
C31: 4.7uF; C0603_B
J14: CONN_03; 1X03
J15, J16: CONN_02; 1X02
L4: 3.3µH; 0805
R19, R42, R43, R45, R46, R51, R53, R56, R57: 33R; R0402_B
R23: 12.4k; R0402_B
R24, R25, R60: 10k; R0402_B
R26: 1M; R0402_B
R31, R39, R40, R41: 49R9; R0402_B
R32: 10R; R0402_B
R47, R48: 330R; R0402_B
R49: 10K; R0402_B
R50: 0R; R-0402S
R59: ?10k; R0402_B
RJ45: HY931147A; ARDUINO-ETHERNET-SHIELD2-V2_CONNETTORI_POE-RJ45
RN1, RN2: 10k; 4X0402ARV341
U1: W5500
Y1: 25MHz; CRYSTAL-SMD-3.2X2.5MM

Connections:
!ETH_INT: R25.1, U1.36 (INT_N); also elsewhere on the board
!RESET: C30.2, R49.1, R56.1, U1.37 (RST_N)
+3V3: C13.2, C25.1, C33.2, L4.1, R24.2, R25.2, R49.2, R59.2, R60.2, RJ45.11 (L1Y+), RJ45.13 (L3G+), RN2.2 (1), RN2.3 (1), RN2.4 (1), U1.28 (VDD); also elsewhere on the board
+3V3A: C18.2, C19.2, C20.2, C21.2, C22.2, C23.2, C28.1, L4.2, R31.2, R32.2, R39.2, U1.4 (AVDD), U1.8 (AVDD), U1.11 (AVDD), U1.15 (AVDD), U1.17 (AVDD), U1.21 (AVDD)
ACTLED: R48.2, U1.27 (ACTLED)
ADC7: R56.2; also elsewhere on the board
CHGND: C29.P$1, RJ45.CH1, RJ45.CH2
ETH_CS: R57.2; also elsewhere on the board
ETH_MISO: R51.2; also elsewhere on the board
ETH_MOSI: R19.2; also elsewhere on the board
ETH_SCK: R53.2; also elsewhere on the board
GND: C1.1, C11.1, C12.1, C13.1, C14.1, C18.1, C19.1, C20.1, C21.1, C22.1, C23.1, C25.2, C26.1, C28.2, C29.P$2, C30.1, C31.2, C33.1, J14.2, J14.3, J15.1, J15.2, R23.1, RN1.1, RN1.2 (1), RN1.3 (1), RN1.4 (1), RN2.1, U1.3 (AGND), U1.9 (AGND), U1.14 (AGND), U1.16 (AGND), U1.19 (AGND), U1.23 (RSVD), U1.29 (GND), U1.48 (AGND), Y1.2 (3), Y1.4 (3); also elsewhere on the board
LINKLED: R47.2, U1.25 (LINKLED)
unnamed: R19.1, R60.1, U1.35 (MOSI)
unnamed: R51.1, R59.1, U1.34 (MISO)
unnamed: RN1.8 (2), U1.38 (RSVD)
unnamed: R53.1, U1.33 (SCLK)
unnamed: RN1.7 (2), U1.39 (RSVD)
unnamed: RN1.6 (2), U1.40 (RSVD)
unnamed: RN1.5 (2), U1.41 (RSVD)
unnamed: RN2.8 (2), U1.42 (RSVD)
unnamed: R24.1, R57.1, U1.32 (SCS_N)
unnamed: RN2.7 (2), U1.43 (PMODE2)
unnamed: RN2.6 (2), U1.44 (PMODE1)
unnamed: RN2.5 (2), U1.45 (PMODE0)
unnamed: C26.2, U1.22 (1V2O)
unnamed: R23.2, U1.10 (EXRES1)
unnamed: C1.2, R32.1, RJ45.R4 (TCT)
unnamed: C14.2, R40.1, R41.1, RJ45.R3 (RCT)
unnamed: R26.1, R50.1, U1.31 (XO)
unnamed: C11.2, R26.2, U1.30 (XI/CLKIN), Y1.3 (2)
unnamed: C12.2, R50.2, Y1.1
unnamed: C31.1, U1.20 (TOCAP)
unnamed: R48.1, RJ45.12 (L2Y-)
unnamed: R47.1, RJ45.14 (L4G-)
RR_N: C16.2, RJ45.R1 (RD-)
RR_P: C15.2, RJ45.R2 (RD+)
RX_N: C16.1, R41.2, R46.1
RX_P: C15.1, R40.2, R45.1
R_N: R46.2, U1.5 (RXN)
R_P: R45.2, U1.6 (RXP)
TX_N: R31.1, R43.1, RJ45.R5 (TD-)
TX_P: R39.1, R42.1, RJ45.R6 (TD+)
T_N: R43.2, U1.1 (TXN)
T_P: R42.2, U1.2 (TXP)
V+: J16.2, RJ45.R9 (V+)
V-: J16.1, RJ45.R10 (V-)
VPOE: J14.1; also elsewhere on the board

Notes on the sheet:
From PoE module
To PoE module
Ethernet

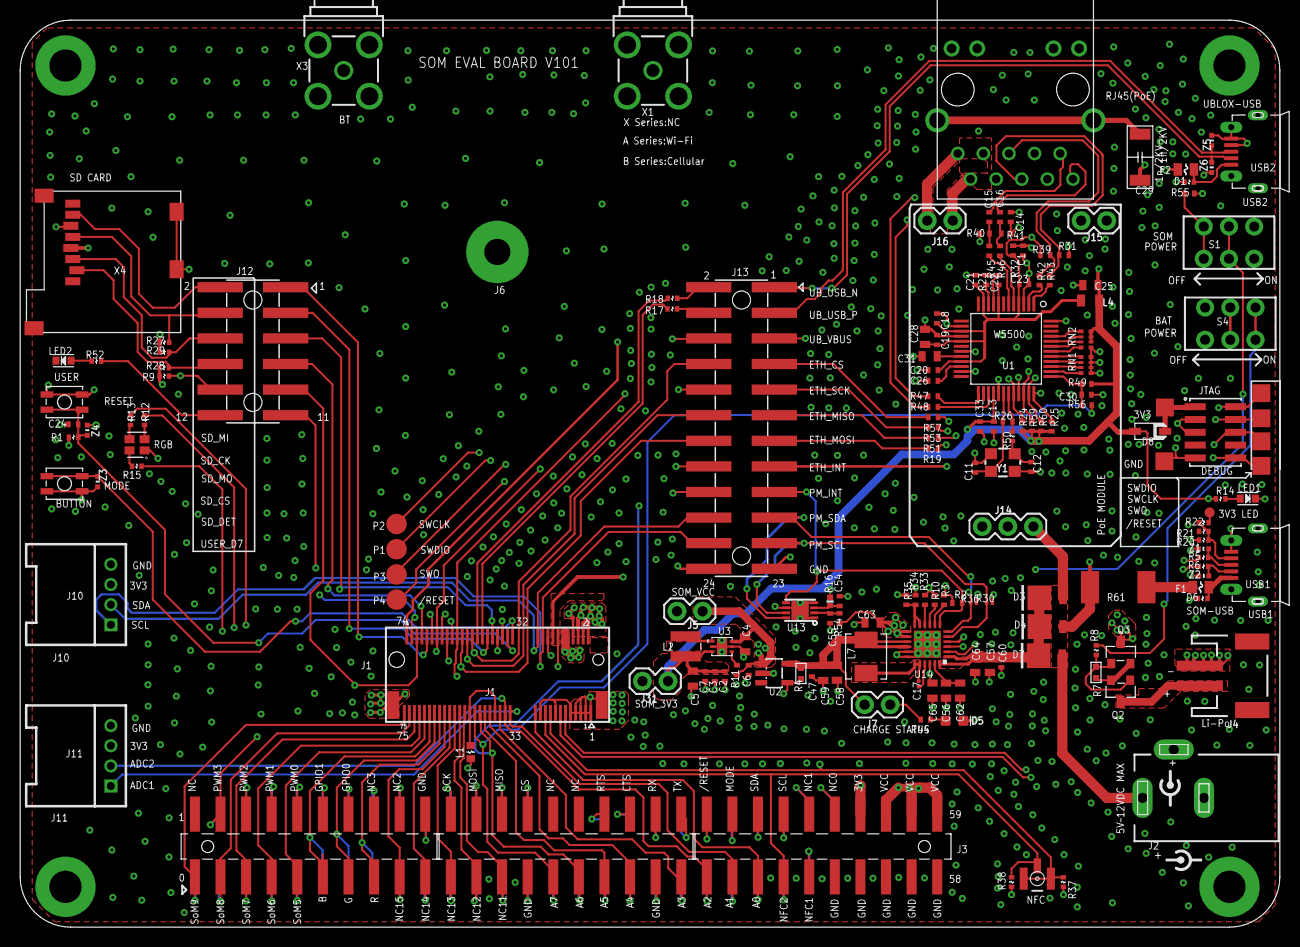
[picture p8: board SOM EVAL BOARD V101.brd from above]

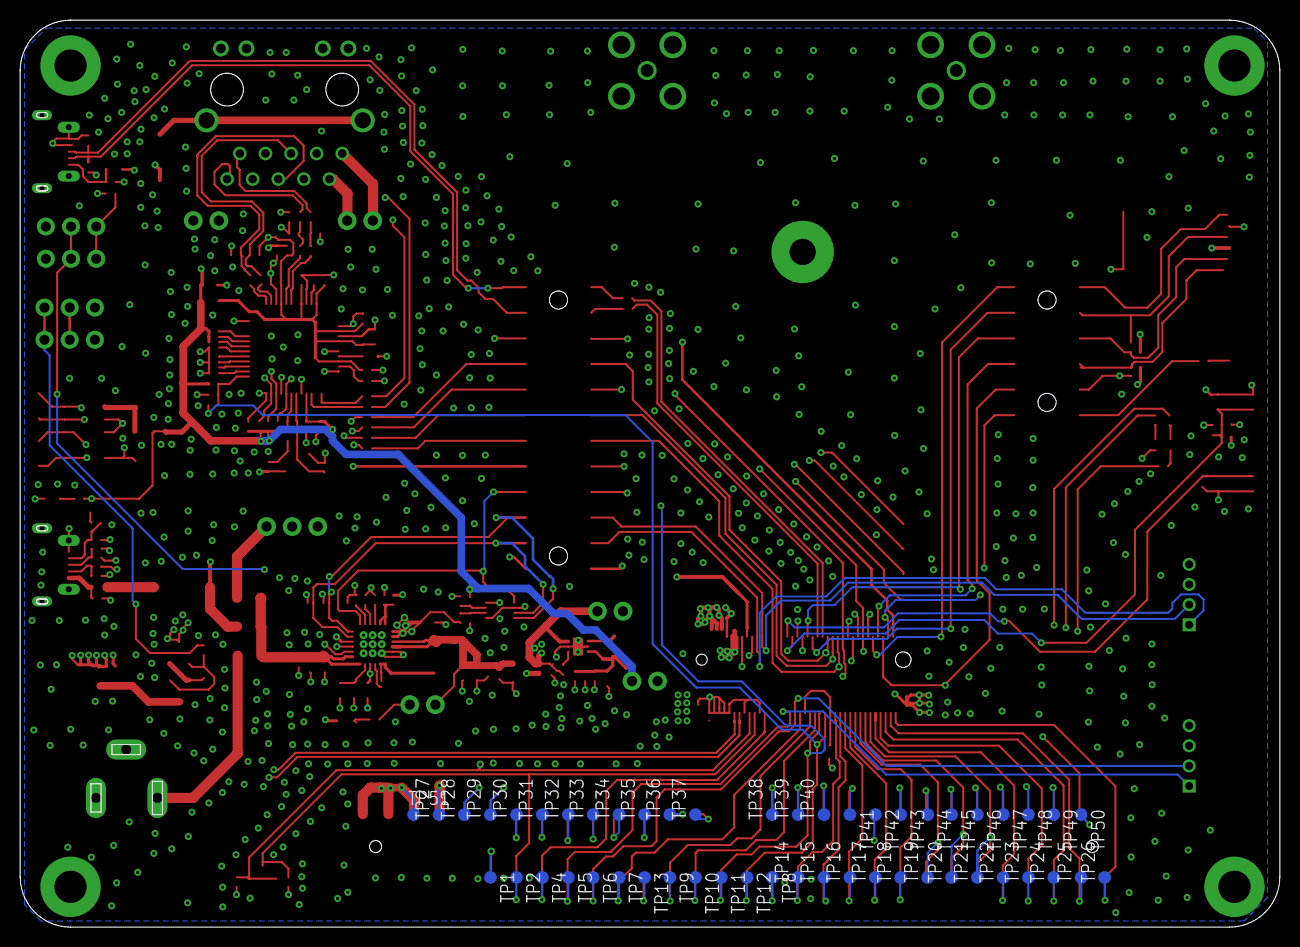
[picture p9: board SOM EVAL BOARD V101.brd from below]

Board: 4 copper layers, 125.0 x 90.0 mm, 220 parts (56 on the bottom side), 158 nets.

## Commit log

2019-10-03 initial version
    [SOM EVAL BOARD V006.GBL, SOM EVAL BOARD V006.GBO, SOM EVAL BOARD V006.GBP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]
2019-12-18 Updated to version 1.0.1 of eval board
    [SOM EVAL BOARD V006.GBL, SOM EVAL BOARD V006.GBS, SOM EVAL BOARD V006.GTL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]
2021-01-28 Added v1.1 board
    [SOM EVAL BOARD V1.1.brd, SOM EVAL BOARD V1.1.sch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]

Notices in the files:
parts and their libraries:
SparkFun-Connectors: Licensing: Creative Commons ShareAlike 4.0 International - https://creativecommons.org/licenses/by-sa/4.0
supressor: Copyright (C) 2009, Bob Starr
